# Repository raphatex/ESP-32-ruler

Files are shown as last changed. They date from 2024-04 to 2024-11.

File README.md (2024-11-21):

# ESP-32-ruler
PCB ruler featuring an ESP-32 module, push-buttons and an OLED screen

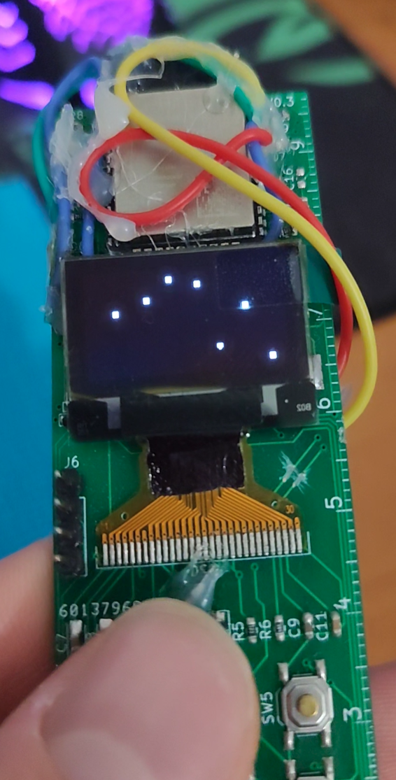
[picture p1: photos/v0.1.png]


Tetris on the Ruler

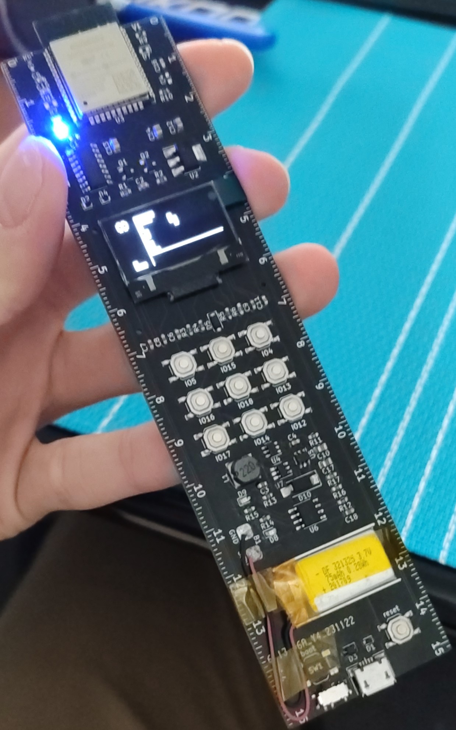
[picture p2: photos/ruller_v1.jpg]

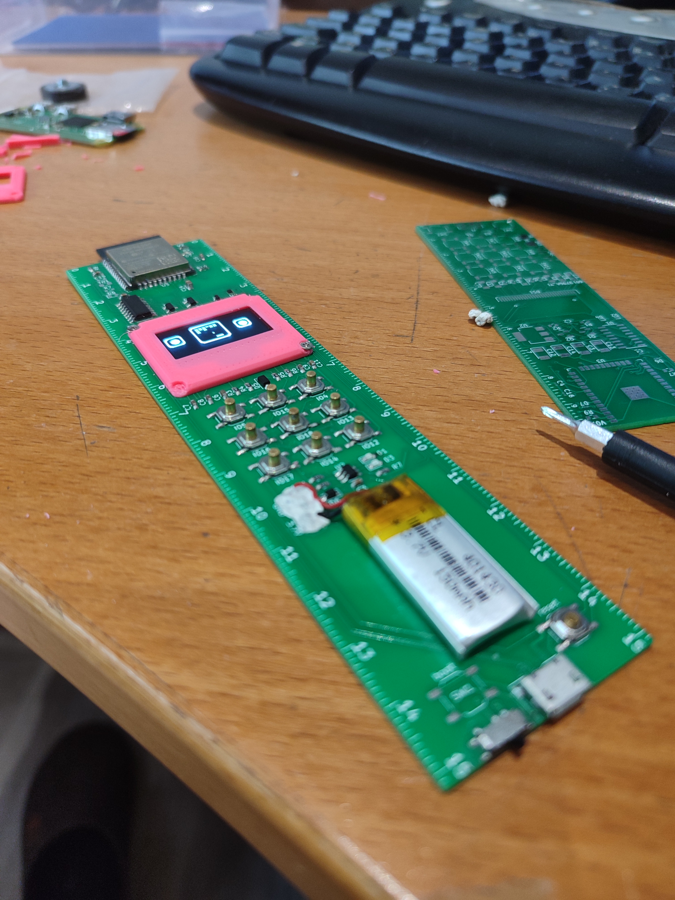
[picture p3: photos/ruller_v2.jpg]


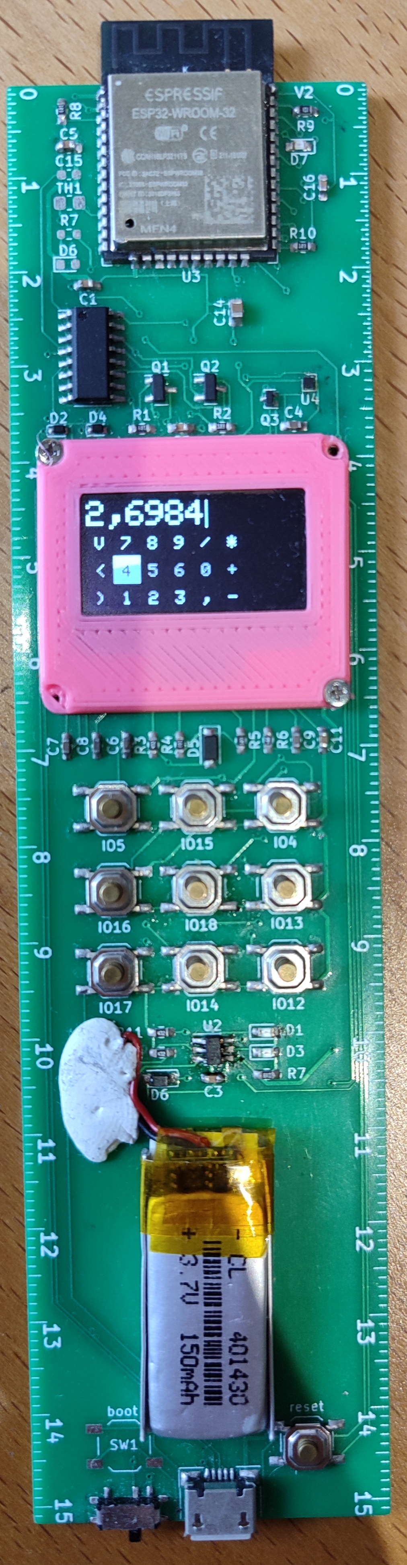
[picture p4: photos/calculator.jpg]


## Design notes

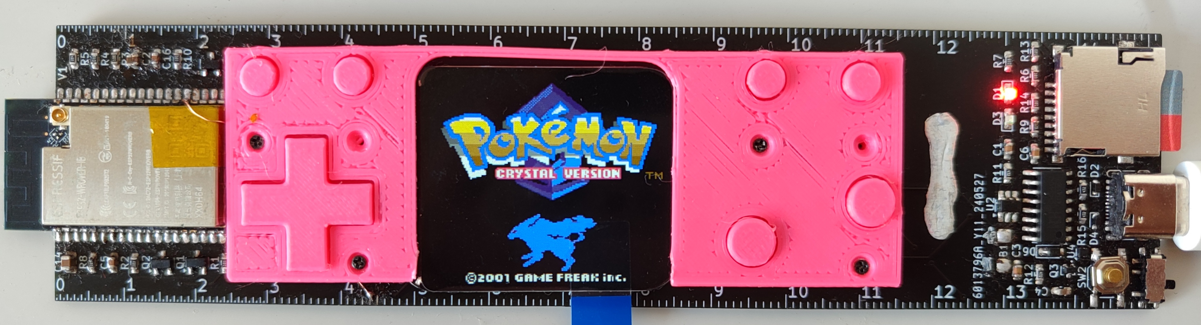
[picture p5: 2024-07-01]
photos/pokemon.jpg

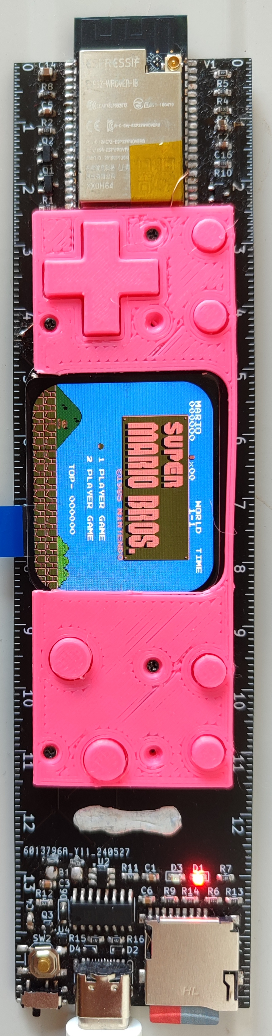
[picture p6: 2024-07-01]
photos/mario.jpg

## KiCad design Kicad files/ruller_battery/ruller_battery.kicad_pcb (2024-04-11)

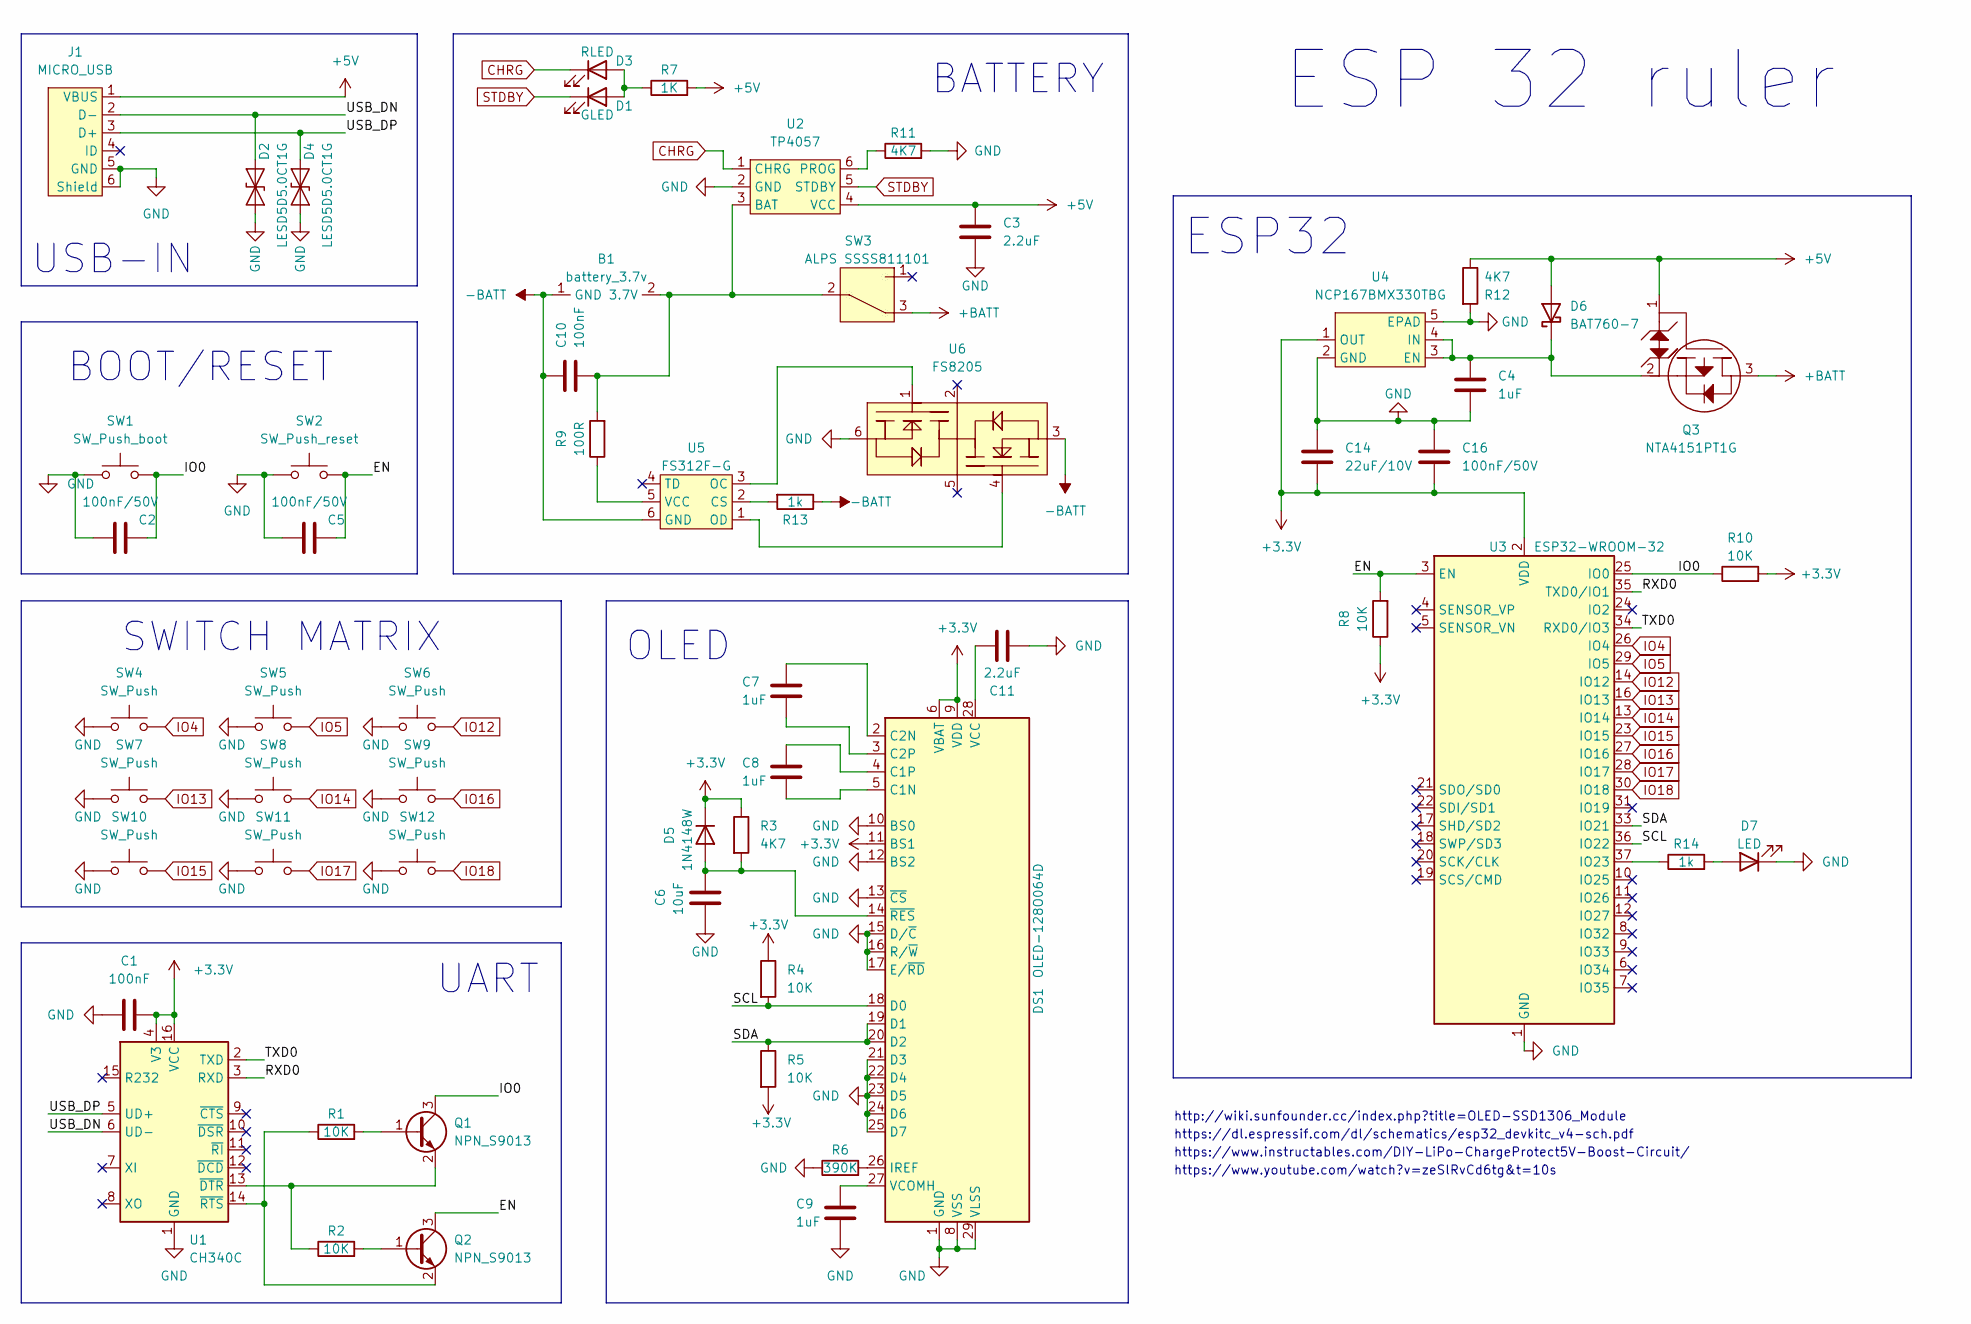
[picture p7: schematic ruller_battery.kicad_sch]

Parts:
B1: battery_3.7v; battery 3.7v
C1, C10: 100nF; C_0603_1608Metric_Pad1.08x0.95mm_HandSolder
C2, C5, C16: 100nF/50V; C_0603_1608Metric_Pad1.08x0.95mm_HandSolder
C3, C11: 2.2uF; C_0603_1608Metric_Pad1.08x0.95mm_HandSolder
C4, C7, C8, C9: 1uF; C_0603_1608Metric_Pad1.08x0.95mm_HandSolder
C6: 10uF; C_0603_1608Metric_Pad1.08x0.95mm_HandSolder
C14: 22uF/10V; C_0805_2012Metric
D1: RLED; LED_0603_1608Metric_Pad1.05x0.95mm_HandSolder
D2, D4: LESD5D5.0CT1G; D_SOD-523
D3: GLED; LED_0603_1608Metric_Pad1.05x0.95mm_HandSolder
D5: 1N4148W; D_SOD-123
D6: BAT760-7; D_SOD-323_HandSoldering
D7: LED; LED_0603_1608Metric_Pad1.05x0.95mm_HandSolder
DS1: OLED-128O064D
J1: MICRO_USB; MICRO USB
Q1, Q2: NPN_S9013; SOT-23
Q3: NTA4151PT1G; SOT-416
R1, R2, R4, R5, R8, R10: 10K; R_0603_1608Metric_Pad0.98x0.95mm_HandSolder
R3, R11, R12: 4K7; R_0603_1608Metric_Pad0.98x0.95mm_HandSolder
R6: 390K; R_0603_1608Metric_Pad0.98x0.95mm_HandSolder
R7: 1K; R_0603_1608Metric_Pad0.98x0.95mm_HandSolder
R9: 100R; R_0603_1608Metric_Pad0.98x0.95mm_HandSolder
R13, R14: 1k; R_0603_1608Metric_Pad0.98x0.95mm_HandSolder
SW1: SW_Push_boot; SW_SPST_TL3342
SW2: SW_Push_reset; SW_SPST_TL3342
SW3: ALPS SSSS811101; SW7_6.7X4.1MM_SM SSSS811101
SW4, SW5, SW6, SW7, SW8, SW9, SW10, SW11, SW12: SW_Push; SW_SPST_TL3342
U1: CH340C; SOIC-16_3.9x9.9mm_P1.27mm
U2: TP4057; SOT-23-6_Handsoldering
U3: ESP32-WROOM-32
U4: NCP167BMX330TBG; OnSemi_XDFN4-1EP_1.0x1.0mm_EP0.52x0.52mm
U5: FS312F-G
U6: FS8205

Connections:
+3.3V: C1.2, C14.1, C16.2, D5.1 (K), DS1.6 (VBAT), DS1.9 (VDD), DS1.11 (BS1), R3.1, R4.1, R5.2, R8.1, R10.2, U1.4 (V3), U1.16 (VCC), U3.2 (VDD), U4.1 (OUT)
+5V: C3.1, D6.2 (A), J1.1 (VBUS), Q3.1, R7.2, R12.1, U2.4 (VCC); also elsewhere on the board
+BATT: Q3.3, SW3.3
/EN: C5.2, Q2.3 (C), R8.2, SW2.2, U3.3 (EN); also elsewhere on the board
/IO0: C2.2, Q1.3 (C), R10.1, SW1.2, U3.25 (IO0)
/RXD0: U1.3 (RXD), U3.35 (TXD0/IO1)
/SCL: DS1.18 (D0), R4.2, U3.36 (IO22)
/SDA: DS1.19 (D1), DS1.20 (D2), R5.1, U3.33 (IO21)
/TXD0: U1.2 (TXD), U3.34 (RXD0/IO3)
/USB_DN: D2.2 (A2), J1.2 (D-), U1.6 (UD-)
/USB_DP: D4.2 (A2), J1.3 (D+), U1.5 (UD+)
CHRG: D1.1 (K), U2.1 (CHRG)
IO4: SW4.2, U3.26 (IO4)
IO5: SW5.2, U3.29 (IO5)
IO12: SW6.2, U3.14 (IO12)
IO13: SW7.2, U3.16 (IO13)
IO14: SW8.2, U3.13 (IO14)
IO15: SW10.2, U3.23 (IO15)
IO16: SW9.2, U3.27 (IO16)
IO17: SW11.2, U3.28 (IO17)
IO18: SW12.2, U3.30 (IO18)
unnamed: C6.1, D5.2 (A), DS1.14 (~RES), R3.2
unnamed: C7.1, DS1.2 (C2N)
unnamed: C7.2, DS1.3 (C2P)
unnamed: C8.1, DS1.4 (C1P)
unnamed: C8.2, DS1.5 (C1N)
unnamed: C9.1, DS1.27 (VCOMH)
unnamed: C11.1, DS1.28 (VCC)
unnamed: D1.2 (A), D3.2 (A), R7.1
unnamed: DS1.26 (IREF), R6.2
unnamed: Q1.1 (B), R1.2
unnamed: Q1.2 (E), R2.1, U1.13 (~DTR)
unnamed: Q2.1 (B), R2.2
unnamed: Q2.2 (E), R1.1, U1.14 (~RTS)
unnamed: C4.1, D6.1 (K), Q3.2, U4.3 (EN), U4.4 (IN)
unnamed: R9.1, R14.1, U3.37 (IO23), U5.5 (VCC)
unnamed: R11.1, U2.6 (PROG)
unnamed: R13.2, U5.2 (CS)
unnamed: U5.1 (OD), U6.4
unnamed: U5.3 (OC), U6.1
STDBY: D3.1 (K), U2.5 (STDBY)

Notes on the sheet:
https://www.youtube.com/watch?v=zeSlRvCd6tg&t=10s
BATTERY
http://wiki.sunfounder.cc/index.php?title=OLED-SSD1306_Module
https://dl.espressif.com/dl/schematics/esp32_devkitc_v4-sch.pdf
BOOT/RESET
UART
https://www.instructables.com/DIY-LiPo-ChargeProtect5V-Boost-Circuit/
SWITCH MATRIX
ESP 32 ruler
ESP32
USB-IN
OLED

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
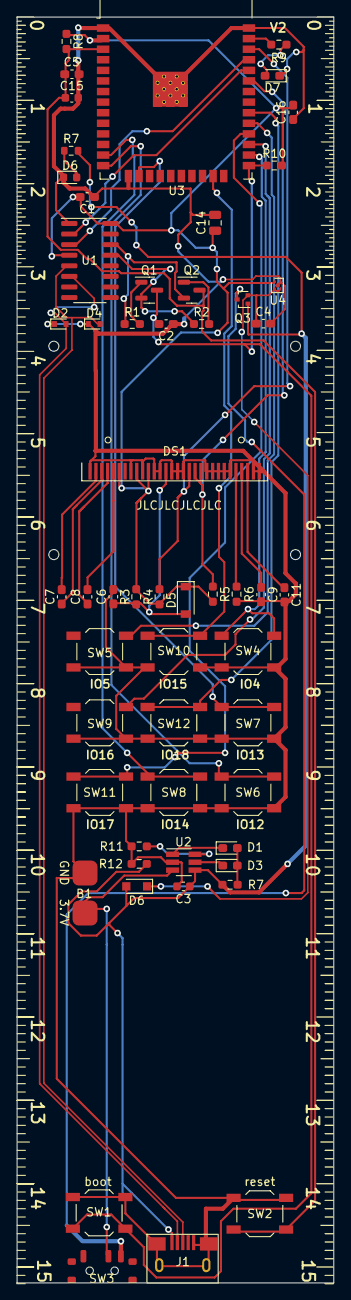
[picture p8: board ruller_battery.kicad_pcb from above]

Board: 2 copper layers, 38.0 x 151.9 mm, 56 parts (0 on the bottom side), 42 nets.

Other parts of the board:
C15: 100nF/50V; C_0603_1608Metric
D6#2: LED; LED_0603_1608Metric
R7#2: 1k; R_0603_1608Metric

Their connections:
+5V: R7#2.2; also elsewhere on the board
/EN: C15.1; also elsewhere on the board
unnamed: D6#2.2 (A), R7#2.1

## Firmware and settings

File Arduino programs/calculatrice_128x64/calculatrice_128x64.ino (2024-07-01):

// https://www.geeksforgeeks.org/convert-floating-point-number-string/

#include <SPI.h>
#include <Wire.h>
#include <Adafruit_GFX.h>
#include <Adafruit_SSD1306.h>

#define SCREEN_WIDTH 128 // OLED display width, in pixels
#define SCREEN_HEIGHT 64 // OLED display height, in pixels

#define OLED_RESET     4 // Reset pin # (or -1 if sharing Arduino reset pin)
#define SCREEN_ADDRESS 0x3C
Adafruit_SSD1306 display(SCREEN_WIDTH, SCREEN_HEIGHT, &Wire, OLED_RESET);

#define HAUT 1
#define BAS 7
#define DROITE 5
#define GAUCHE 3
#define A 4
#define EXIT 2
#define EGAL 0
#define C 6

int buttons[] = {5, 15, 4, 16, 18, 13, 17, 14, 12};
// int buttons[] = {17, 15, 5, 14, 18, 16, 12, 13, 4}; old_version
int buttonsState[] = {0,0,0,0,0,0,0,0,0};

void checkButtons(){
  for(int i = 0; i < 9; i++){
    buttonsState[i] = !digitalRead(buttons[i]);
  }
}

#define MAX 10
bool bool_bouton = 1;

int x = 1;
int y = 1;

float number1 = 0;
float number2 = 0;
float result;
int digit = 0;
bool virgule = 0;
int float_power;

unsigned long lastime;
int operand = 1;
bool black = 0;
bool displaying_result = 0;

const char* ui[3][6] = {
  {"V","7","8","9","/","*"},
  {"<","4","5","6","0","+"},
  {")","1","2","3",",","-"}
};

void erase(int x, int y){
  display.setTextSize(1);
  display.fillRect(16*x, 16*y+16, 16, 16, SSD1306_BLACK);
  display.setCursor(x*16+5,y*16+21);
  display.setTextColor(SSD1306_WHITE);
  display.print(ui[y][x]);
}

void draw(int x, int y){
  display.setTextSize(1);
  display.fillRect(16*x, 16*y+16, 16, 16, SSD1306_WHITE);
  display.setCursor(x*16+5,y*16+21);
  display.setTextColor(SSD1306_BLACK);
  display.print(ui[y][x]);
}

// Reverses a string 'str' of length 'len' 
void reverse(char* str, int len){ 
    int i = 0, j = len - 1, temp; 
    while (i < j) { 
        temp = str[i]; 
        str[i] = str[j]; 
        str[j] = temp; 
        i++; 
        j--; 
    } 
} 
 
// Converts a given integer x to string str[]. 
// d is the number of digits required in the output. 
// If d is more than the number of digits in x, 
// then 0s are added at the beginning. 
int intToStr(int x, char str[], int d){ 
    int i = 0; 

    if (x == 0){
      str[0] = '0';
      str[1] = '\0';
    }

    else{
      while (x) { 
          str[i++] = (x % 10) + '0'; 
          x = x / 10; 
      }
  
      // If number of digits required is more, then 
      // add 0s at the beginning 
      while (i < d) 
          str[i++] = '0'; 

      reverse(str, i); 
      str[i] = '\0'; 
    }

    return i; 
} 
 
// Converts a floating-point/double number to a string. 
int ftoa(float n, char* res){ 
    // Extract integer part 
    int ipart = (int)n; 
 
    // Extract floating part 
    float fpart = n - (float)ipart; 
 
    // convert integer part to string 
    int i = intToStr(ipart, res, 0); 

    int nb_int = i;

    // check if float part is needed
    i = 0; 
    int float_part = 0;
    int x = int(fpart * pow(10, MAX-nb_int-1));

    while (x) { 
        float_part += x % 10;
        x = x / 10; 
    }

    // check for display option after point 
    if (float_part) { 
      res[nb_int] = '.'; // add dot 

      // Get the value of fraction part upto given no. 
      // of points after dot. The third parameter 
      // is needed to handle cases like 233.007 
      fpart = fpart * pow(10, MAX-nb_int-1); 

      intToStr((int)fpart, res + nb_int + 1, MAX-nb_int-1);
    }

    nb_int += i;
    return nb_int;
} 

void display_char(char c){
  display.drawLine(digit*12, 0, digit*12, 15, SSD1306_BLACK);
  display.setTextSize(2);
  display.setCursor(digit*12,0);
  display.setTextColor(SSD1306_WHITE);
  display.print(c);
  display.display();
}

void handle_keys(int x, int y){
  int pos = x + y*6;
  int chiffre = -1;
  bool operation = 0;

  switch(pos){
    case 0:
      // v
      if (displaying_result)
        result = sqrt(result);
      else
        result = sqrt(number1);
      display.fillRect(0, 0, 128, 16, SSD1306_BLACK);
      displaying_result = 1;
      virgule = 0;
      digit = 0;
      
      displ_nbr(result);
      break;

    case 1:
      // 7
      chiffre = 7;
      break;

    case 2:
      // 8
      chiffre = 8;
      break;

    case 3:
      // 9
      chiffre = 9;
      break;

    case 4:
      // /
      operand = 0;
      operation = 1;
      break;

    case 5:
      // *
      operand = 1;
      operation = 1;
      break;

    case 6:
      // <-

      break;

    case 7:
      // 4
      chiffre = 4;
      break;

    case 8:
      // 5
      chiffre = 5;
      break;

    case 9:
      // 6
      chiffre = 6;
      break;

    case 10:
      // 0
      chiffre = 0;
      break;

    case 11:
      // +
      operand = 2;
      operation = 1;
      break;

    case 12:
      // )

      break;

    case 13:
      // 1
      chiffre = 1;
      break;

    case 14:
      // 2
      chiffre = 2;
      break;

    case 15:
      // 3
      chiffre = 3;
      break;

    case 16:
      // ,
      if(!virgule){
        virgule = 1;
        float_power = 1;
        display_char(',');
        digit++;
      }
      break;
    
    case 17:
      // -
      operand = 3;
      operation = 1;
      break;
  }

  if (chiffre != -1 and digit <= 9){
    if (displaying_result){
      display.fillRect(0, 0, 128, 16, SSD1306_BLACK);
      displaying_result = 0;
    }
    
    if (!virgule){
      number1 = number1*10;
      number1 += chiffre;
    }

    else{
      number1 += chiffre*pow(0.1, float_power);
      float_power++;
    }

    display_char(chiffre+'0');
    digit++;
    display.drawLine(digit*12, 0, digit*12, 15, SSD1306_WHITE);
  }

  if(operation){
    if(displaying_result == 1)
      number2 = result;
    else
      number2 = number1;
    number1 = 0;
    digit = 0;
    display.fillRect(0, 0, 128, 16, SSD1306_BLACK);
    displaying_result = 0;
    virgule = 0;
    display.drawLine(digit*12, 0, digit*12, 15, SSD1306_WHITE);
  }
}

void displ_nbr(float nombre){
  char buf[MAX+1];
  ftoa(nombre, buf);
  display.setTextSize(2);
  display.fillRect(0, 0, 128, 16, SSD1306_BLACK);
  display.setCursor(0,0);
  display.setTextColor(SSD1306_WHITE);
  display.print(buf);
  display.display();
}

void setup(){
  Serial.begin(115200);
  lastime = millis();

  for(int i = 0; i < 9; i++){
    pinMode(buttons[i], INPUT_PULLUP);
  }
  display.begin(SSD1306_SWITCHCAPVCC, SCREEN_ADDRESS);

  display.clearDisplay();
  display.setTextColor(SSD1306_WHITE);
  display.setTextSize(1);

  for(int x = 0; x <= 5; x++){
    for(int y = 0; y <= 2; y++){
    display.setCursor(x*16+5,y*16+21);
    display.print(ui[y][x]);
    }
  }

  display.fillRect(16*x, 16*y+16, 16, 16, SSD1306_WHITE);
  display.setCursor(x*16+5,y*16+21);
  display.setTextColor(SSD1306_BLACK);
  display.print(ui[y][x]);

  display.drawLine(digit*12, 0, digit*12, 15, SSD1306_WHITE);
}

void loop(){
  if(millis()-lastime >= 400 and !displaying_result){
    lastime = millis();
    if(black){
      black = 0;
      display.drawLine(digit*12, 0, digit*12, 15, SSD1306_BLACK);
    }
    else{
      black = 1;
      display.drawLine(digit*12, 0, digit*12, 15, SSD1306_WHITE);
    }
    
  }

  checkButtons();
  if(bool_bouton){
    bool_bouton = 0;

    if(buttonsState[HAUT]){
      erase(x, y);
      if(y >= 1){
        y -= 1;
      }
      else{
        y = 2; 
      }
      draw(x, y);
    }

    if(buttonsState[BAS]){
      erase(x, y);
      if(y <= 1){
        y += 1;
      }
      else{
        y = 0; 
      }
      draw(x, y);
    }

    if(buttonsState[GAUCHE]){
      erase(x, y);
      if(x >= 1){
        x -= 1;
      }
      else{
        x = 5; 
      }
      draw(x, y);
    }

    if(buttonsState[DROITE]){
      erase(x, y);
      if(x <= 4){
        x += 1;
      }
      else{
        x = 0; 
      }
      draw(x, y);
    }

    if(buttonsState[A]){
      handle_keys(x,y);
    }

    if(buttonsState[EGAL]){
      switch(operand){
        case 0:
          // /
          if (number1 == 0){
            result = 0;
          }
          else{
            result = number2/number1;
          }
          break;

        case 1:
          // *
          result = number1*number2;
          break;

        case 2:
          // +
          result = number1+number2;
          break;

        case 3:
          // -
          result = number2-number1;
          break;
      }
      displ_nbr(result);
      number1 = 0;
      number2 = 0;
      digit = 0;
      virgule = 0;
      displaying_result = 1;
    }

    if(buttonsState[C]){
      displaying_result = 0;
      number1 = 0;
      number2 = 0;
      digit = 0;
      virgule = 0;
      display.fillRect(0, 0, 128, 16, SSD1306_BLACK);
    }

    display.display();
  }

  if(!buttonsState[HAUT] and !buttonsState[BAS] and !buttonsState[GAUCHE] and !buttonsState[DROITE] and !buttonsState[A] and !buttonsState[EGAL]){
    bool_bouton = 1;
  }
  
  delay(20);
}

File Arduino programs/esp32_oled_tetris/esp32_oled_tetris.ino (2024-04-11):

#include <SPI.h>
#include <Wire.h>
#include <Adafruit_GFX.h>
#include <Adafruit_SSD1306.h>

#define SCREEN_WIDTH 128 // OLED display width, in pixels
#define SCREEN_HEIGHT 64 // OLED display height, in pixels

#define OLED_RESET     4 // Reset pin # (or -1 if sharing Arduino reset pin)
#define SCREEN_ADDRESS 0x3C
Adafruit_SSD1306 display(SCREEN_WIDTH, SCREEN_HEIGHT, &Wire, OLED_RESET);

bool bool_bouton2 = 0;
bool bool_bouton4 = 0;
int buttons[] = {5, 15, 4, 16, 18, 13, 17, 14, 12};
int buttonsState[] = {0,0,0,0,0,0,0,0,0};

void checkButtons(){
  for(int i = 0; i < 9; i++){
    buttonsState[i] = !digitalRead(buttons[i]);
  }
}


int lines[] = {0,0,0,0};
int score = 0;
int pieces_posee = 0;
bool PAUSE = 0;
bool END = 0;
int delai = 500;

int x = 4;
int y = 0;

int rotation = 0;
int piece;
int next_piece;

int last_update = millis();

bool pieces[4][7][4][4] = {{
// 0°
  {{1,0,0,0},
   {1,1,0,0},
   {1,0,0,0},
   {0,0,0,0}},

  {{0,1,0,0},
   {1,1,0,0},
   {1,0,0,0},
   {0,0,0,0}},
   
  {{1,0,0,0},
   {1,1,0,0},
   {0,1,0,0},
   {0,0,0,0}},
   
  {{1,0,0,0},
   {1,0,0,0},
   {1,0,0,0},
   {1,0,0,0}},

  {{1,0,0,0},
   {1,0,0,0},
   {1,1,0,0},
   {0,0,0,0}},

  {{0,1,0,0},
   {0,1,0,0},
   {1,1,0,0},
   {0,0,0,0}},

  {{1,1,0,0},
   {1,1,0,0},
   {0,0,0,0},
   {0,0,0,0}}
},
// 90°
{
  {{1,1,1,0},
   {0,1,0,0},
   {0,0,0,0},
   {0,0,0,0}},

  {{1,1,0,0},
   {0,1,1,0},
   {0,0,0,0},
   {0,0,0,0}},
   
  {{0,1,1,0},
   {1,1,0,0},
   {0,0,0,0},
   {0,0,0,0}},
   
  {{1,1,1,1},
   {0,0,0,0},
   {0,0,0,0},
   {0,0,0,0}},

  {{1,1,1,0},
   {1,0,0,0},
   {0,0,0,0},
   {0,0,0,0}},

  {{1,0,0,0},
   {1,1,1,0},
   {0,0,0,0},
   {0,0,0,0}},

  {{1,1,0,0},
   {1,1,0,0},
   {0,0,0,0},
   {0,0,0,0}}
},
// 180°
{
  {{0,1,0,0},
   {1,1,0,0},
   {0,1,0,0},
   {0,0,0,0}},

  {{0,1,0,0},
   {1,1,0,0},
   {1,0,0,0},
   {0,0,0,0}},
   
  {{1,0,0,0},
   {1,1,0,0},
   {0,1,0,0},
   {0,0,0,0}},
   
  {{1,0,0,0},
   {1,0,0,0},
   {1,0,0,0},
   {1,0,0,0}},

  {{1,1,0,0},
   {0,1,0,0},
   {0,1,0,0},
   {0,0,0,0}},

  {{1,1,0,0},
   {1,0,0,0},
   {1,0,0,0},
   {0,0,0,0}},

  {{1,1,0,0},
   {1,1,0,0},
   {0,0,0,0},
   {0,0,0,0}}
},
// 270°
{
  {{0,1,0,0},
   {1,1,1,0},
   {0,0,0,0},
   {0,0,0,0}},

  {{1,1,0,0},
   {0,1,1,0},
   {0,0,0,0},
   {0,0,0,0}},
   
  {{0,1,1,0},
   {1,1,0,0},
   {0,0,0,0},
   {0,0,0,0}},
   
  {{1,1,1,1},
   {0,0,0,0},
   {0,0,0,0},
   {0,0,0,0}},

  {{0,0,1,0},
   {1,1,1,0},
   {0,0,0,0},
   {0,0,0,0}},

  {{1,1,1,0},
   {0,0,1,0},
   {0,0,0,0},
   {0,0,0,0}},

  {{1,1,0,0},
   {1,1,0,0},
   {0,0,0,0},
   {0,0,0,0}}
}};

bool MAP[21][12] = {
  {1,0,0,0,0,0,0,0,0,0,0,1},
  {1,0,0,0,0,0,0,0,0,0,0,1},
  {1,0,0,0,0,0,0,0,0,0,0,1},
  {1,0,0,0,0,0,0,0,0,0,0,1},
  {1,0,0,0,0,0,0,0,0,0,0,1},
  {1,0,0,0,0,0,0,0,0,0,0,1},
  {1,0,0,0,0,0,0,0,0,0,0,1},
  {1,0,0,0,0,0,0,0,0,0,0,1},
  {1,0,0,0,0,0,0,0,0,0,0,1},
  {1,0,0,0,0,0,0,0,0,0,0,1},
  {1,0,0,0,0,0,0,0,0,0,0,1},
  {1,0,0,0,0,0,0,0,0,0,0,1},
  {1,0,0,0,0,0,0,0,0,0,0,1},
  {1,0,0,0,0,0,0,0,0,0,0,1},
  {1,0,0,0,0,0,0,0,0,0,0,1},
  {1,0,0,0,0,0,0,0,0,0,0,1},
  {1,0,0,0,0,0,0,0,0,0,0,1},
  {1,0,0,0,0,0,0,0,0,0,0,1},
  {1,0,0,0,0,0,0,0,0,0,0,1},
  {1,0,0,0,0,0,0,0,0,0,0,1},
  {1,1,1,1,1,1,1,1,1,1,1,1},
};

void initialisation(){
  for(int i = 0; i < 9; i++){
      pinMode(buttons[i], INPUT_PULLUP);
  }
  Serial.begin(115200);
  if(!display.begin(SSD1306_SWITCHCAPVCC, SCREEN_ADDRESS)) {
    Serial.println(F("SSD1306 allocation failed"));
    for(;;); // Don't proceed, loop forever
  }
  display.clearDisplay();

  randomSeed(analogRead(25));
  piece = random(0,7);
  next_piece = random(0,7);
  display.drawLine(28, 0, 28, 63, SSD1306_WHITE);
  display.drawLine(28, 50, 127, 50, SSD1306_WHITE);
  display.display();
  draw_next_piece();
}

bool check_collision_y(){
  for(int i = 0; i<= 3; i++){
    for(int j = 0; j<= 3; j++){
      if (MAP[i+y+1][j+x+1] == 1 and pieces[rotation][piece][i][j] == 1){
        return 1;
      }
    }
  }
  return 0;
}

bool check_collision_x_moins(){
  if (x <= 0){
    return 1;
  }
  else{
    for(int i = 0; i<= 3; i++){
      for(int j = 0; j<= 3; j++){
        if (i+y <= 20 and j+x <= 11){
          if (MAP[i+y][j+x] == 1 and pieces[rotation][piece][i][j] == 1){
          return 1;
          }
        }
      }
    }
  }
  return 0;
}

bool check_collision_x_plus(){
  for(int i = 0; i<= 3; i++){
    for(int j = 0; j<= 3; j++){
      if (i+y <= 20 and j+x <= 11){
        if (MAP[i+y][j+x+2] == 1 and pieces[rotation][piece][i][j] == 1){
          return 1;
        }
      }
    }
  }
  return 0;
}

bool check_line(){
  bool response = 0;
  for(int i = 0; i<= 3; i++){
    int total = 0;
    for(int j = 1; j<= 10; j++){
      if (i+y <= 19){
        if(MAP[i+y][j] == 1){
          total += 1;
        }
      }
    }
    if (total == 10){
      lines[i] = 1;
      response = 1;
    }
    else{
      lines[i] = 0;
    }
  }
  for(int i = 0; i<=3; i++){
  }
  return response;
}

void delete_lines(){
  for(int i = 0; i<= 3; i++){
    if (lines[i] == 1){
      for(int z = y; z>=1; z--){
        for(int j = 1; j<= 10; j++){
          MAP[i+z][j] = MAP[i+z-1][j];
        }
      }
    }
  }
}

void draw_next_piece(){
  display.fillRect(0, 53, 20, 10, SSD1306_BLACK);
  for(int i = 0; i<= 3; i++){
    for(int j = 0; j<= 3; j++){
      if(pieces[0][next_piece][i][j] == 1){
         display.fillRect(15-i*5,53+j*5, 5, 5, SSD1306_WHITE);
      }
    }
  }
}

void handle_rotation(){
  if(rotation == 3){
      rotation = 0;
    }
    else{
      rotation +=1;
    }
    y -=1;
    if(check_collision_y()){
      if(rotation == 0){
        rotation = 3;
      }
      else{
        rotation -= 1;
      }
      y +=1;
      return;
    }
    y +=1;
    if (piece <=3){
      switch (rotation){
        case 1:
          x -= 1;
          break;
        case 3:
          x -= 1;
          break;
        case 0:
          x += 1;
          break;
        case 2:
          x += 1;
          break;
      }
    }
    x-=1;
    if(check_collision_x_plus()){
      cancel_rotation();
      x+=1;
      return;
    }
    x+=2;
    if(check_collision_x_moins()){
      cancel_rotation();
    }
    x-=1;
}

void cancel_rotation(){
  if (piece <=3){
    switch (rotation){
      case 1:
        x += 1;
        break;
      case 3:
        x += 1;
        break;
      case 0:
        x -= 1;
        break;
      case 2:
        x -= 1;
        break;
    }
  }
  if(rotation == 0){
    rotation = 3;
  }
  else{
    rotation -= 1;
  }
}

void RESET_map(){
  for(int i = 0; i<= 19; i++){
    for(int j = 1; j<= 10; j++){
      MAP[i][j] = 0;
    }
  }
}

void setup() {
  initialisation();
}
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
